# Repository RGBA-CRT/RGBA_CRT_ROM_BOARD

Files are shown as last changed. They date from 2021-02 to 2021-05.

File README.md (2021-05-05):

# RGBA_CRT ROM BOARD
+ 27C322 64Mbit ROM board for 8bit databus system
**※まだ不安定です**
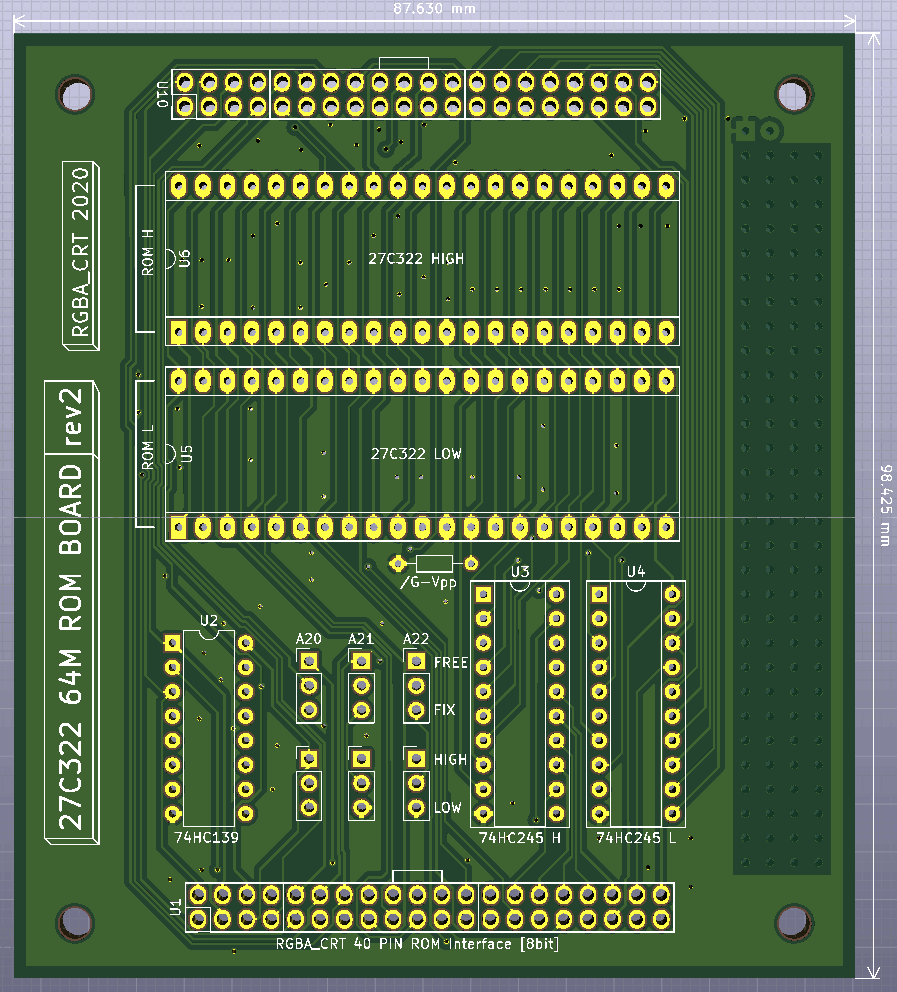
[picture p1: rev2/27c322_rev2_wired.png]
rev2 pcb


# about
+ 27C322を40ピンのピンヘッダに引き出す基板です
+ レトロコンシューマゲーム機やレトロコンピュータでの使用を想定しています
+ 引き出したピンヘッダにはIDC 40ピンリボンケーブルを接続します
	+ IDEケーブル（40芯, 全ピンが結線されているもの）が使用可能です
+ その他
	+ データバスは8bitに変換されます
	+ 27C322を2つ使って64Mbitに対応
	+ ROMのセレクトスイッチ搭載
+ この基板に対応したROMライターはこちら
	+ https://github.com/RGBA-CRT/FT232H-EPROM-Prog

# PIN ROM Interface pinout
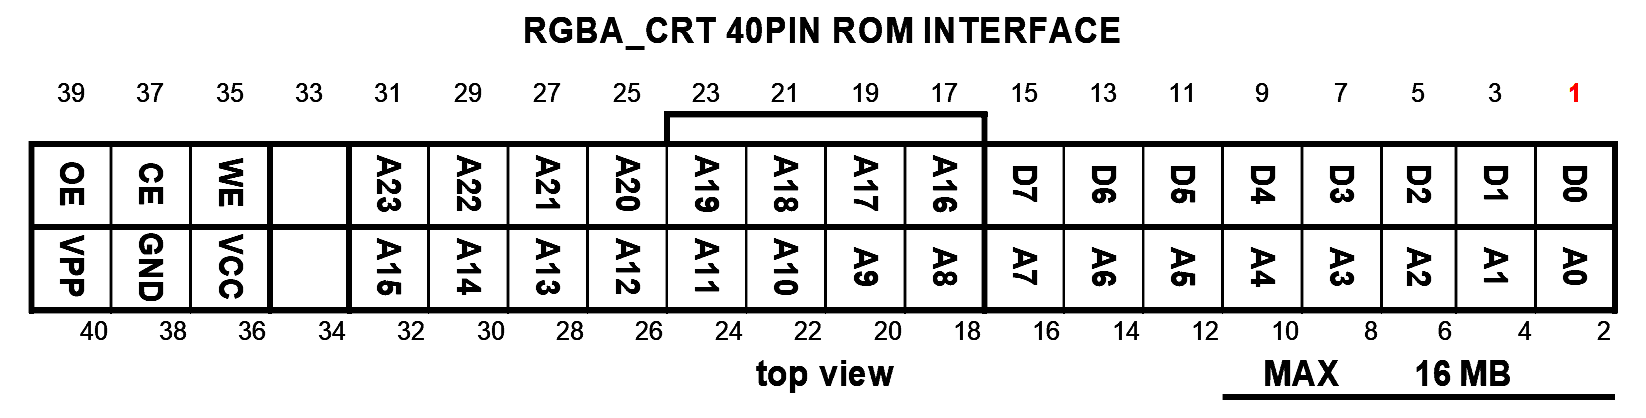
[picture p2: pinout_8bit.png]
pinout 8bit


+ data bus: 8bit
+ address bus: A0-A23 24bit
+ control bus: CE / OE / WE
+ VPP signal supported

# ROM select switch
+ A20, A21, A22の制御スイッチがあります
	+ A20 ... 8Mbit単位切り替え
	+ A21 ... 16Mbit単位切り替え
	+ A22 ... 32Mbit単位切り替え（EPROM切り替え）
+ FREEにするとそのアドレスビットの制御を機器側に委ねます
+ FIXにするとそのアドレスビットの制御をHIGH/LOWスイッチに委ねます
+ 使用例
	+ 1つの64MbitのROMとして基板を使いたい
		+ A20, A21, A22をすべてFREEにする
	+ 4つの16MbitのROMとして基板を使いたい
		+ A20をFREEにする
		+ A21, A22はFIXにする
			+ 2つのHIGH/LOWスイッチで4分割したROMの選択を行う

# 使用例
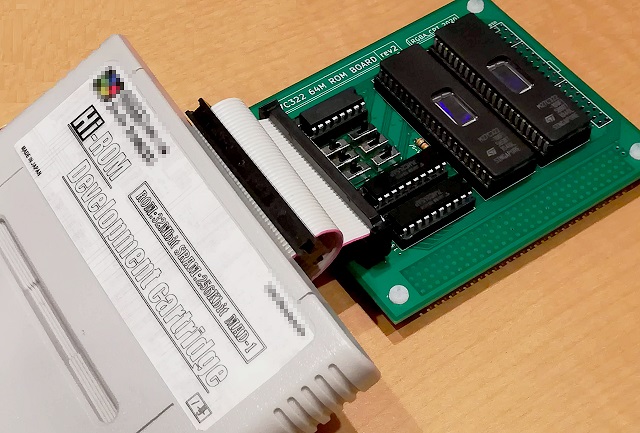
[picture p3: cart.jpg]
connection


# other
+ SNES/SFCのExHiROMとして使用する場合は、ROM焼き時と実機実行時でROM L, ROM Hを逆に取り付ける必要があります。
	+ ROMライターはファイルの順の通り次のように書き込みます
		+ ROM L: SNES BANK $C0-$FF
		+ ROM H: SNES BANK $40-$7F
	+ したがってSFCのカートリッジとして使うときにはROM LとROM Hを逆にする必要があります
+ おまけ
	+ この40 PIN ROM Interfaceに対応したユニバーサル基板
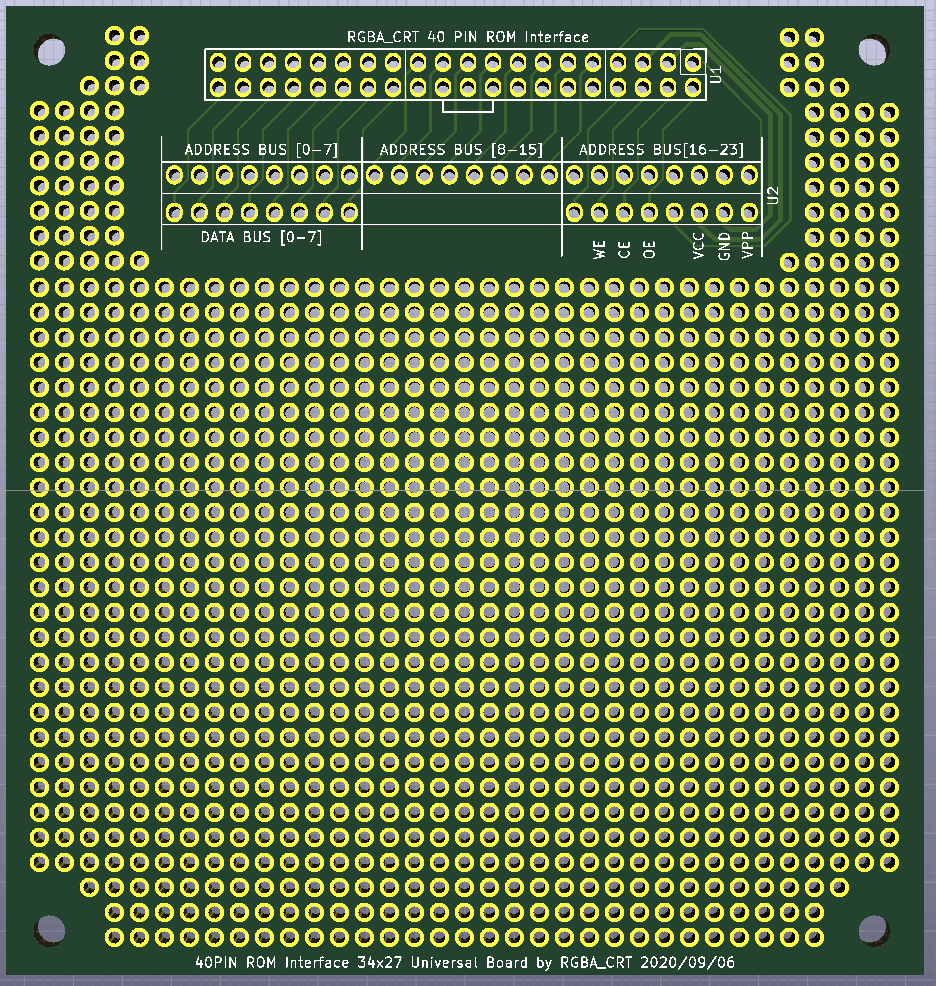
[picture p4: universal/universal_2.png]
univ pcb


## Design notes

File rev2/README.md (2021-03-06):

# RGBA_CRT_ROM_BOARD rev2
+ two ROM
+ 3 ROM select switch
+ low bytes are mapped to 0x0
+ high bytes are mapped to 0x1



# garber
[rev2.zip](rev2.zip)

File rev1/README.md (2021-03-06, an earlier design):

# RGBA_CRT_ROM_BOARD rev1
+ one ROM
+ 2 ROM select switch
+ low bytes are mapped to 0x000000-0x1FFFFF
+ high bytes are mapped to 0x200000-0x3FFFFF

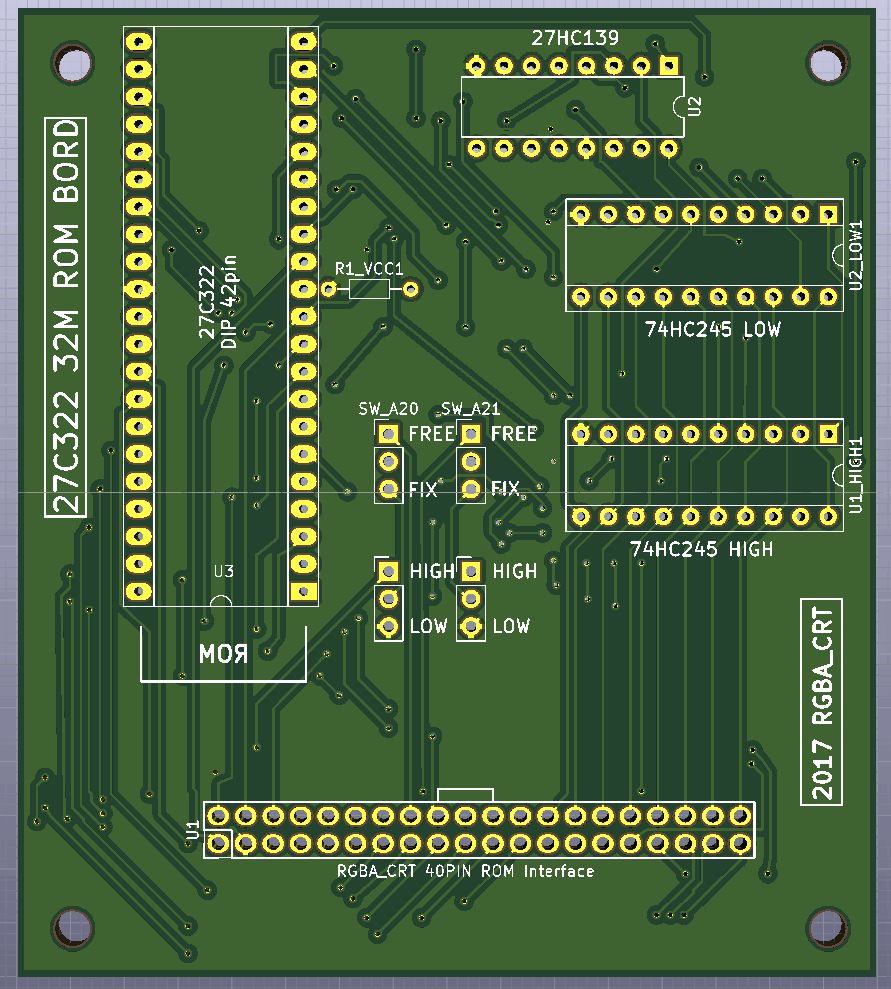
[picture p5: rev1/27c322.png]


# garber
[27c322Bord.zip](27c322Bord.zip)

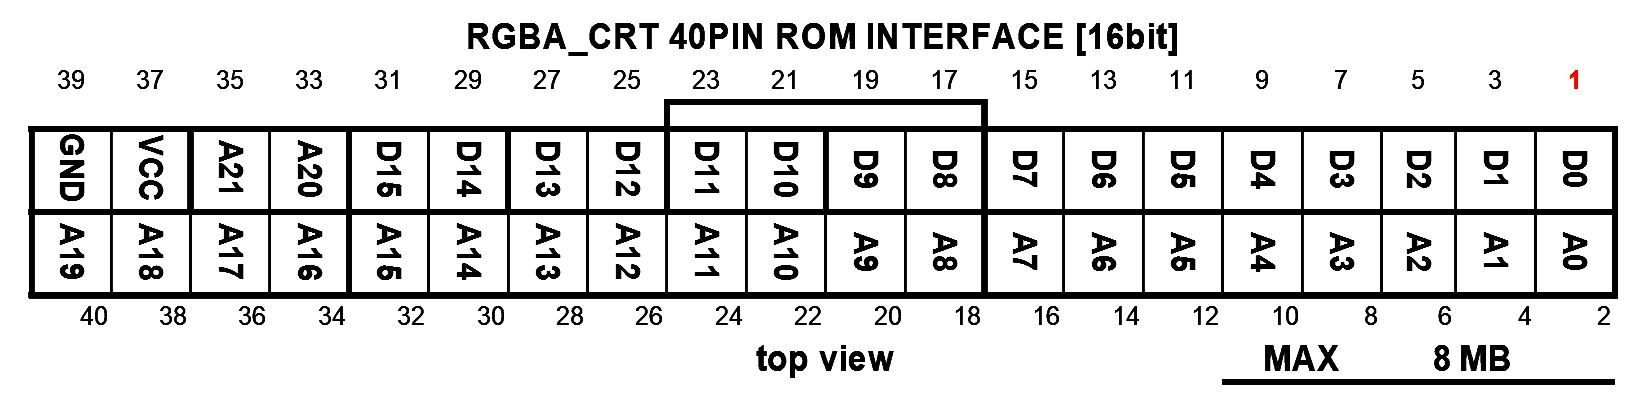
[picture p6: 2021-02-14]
pinout_16bit.png

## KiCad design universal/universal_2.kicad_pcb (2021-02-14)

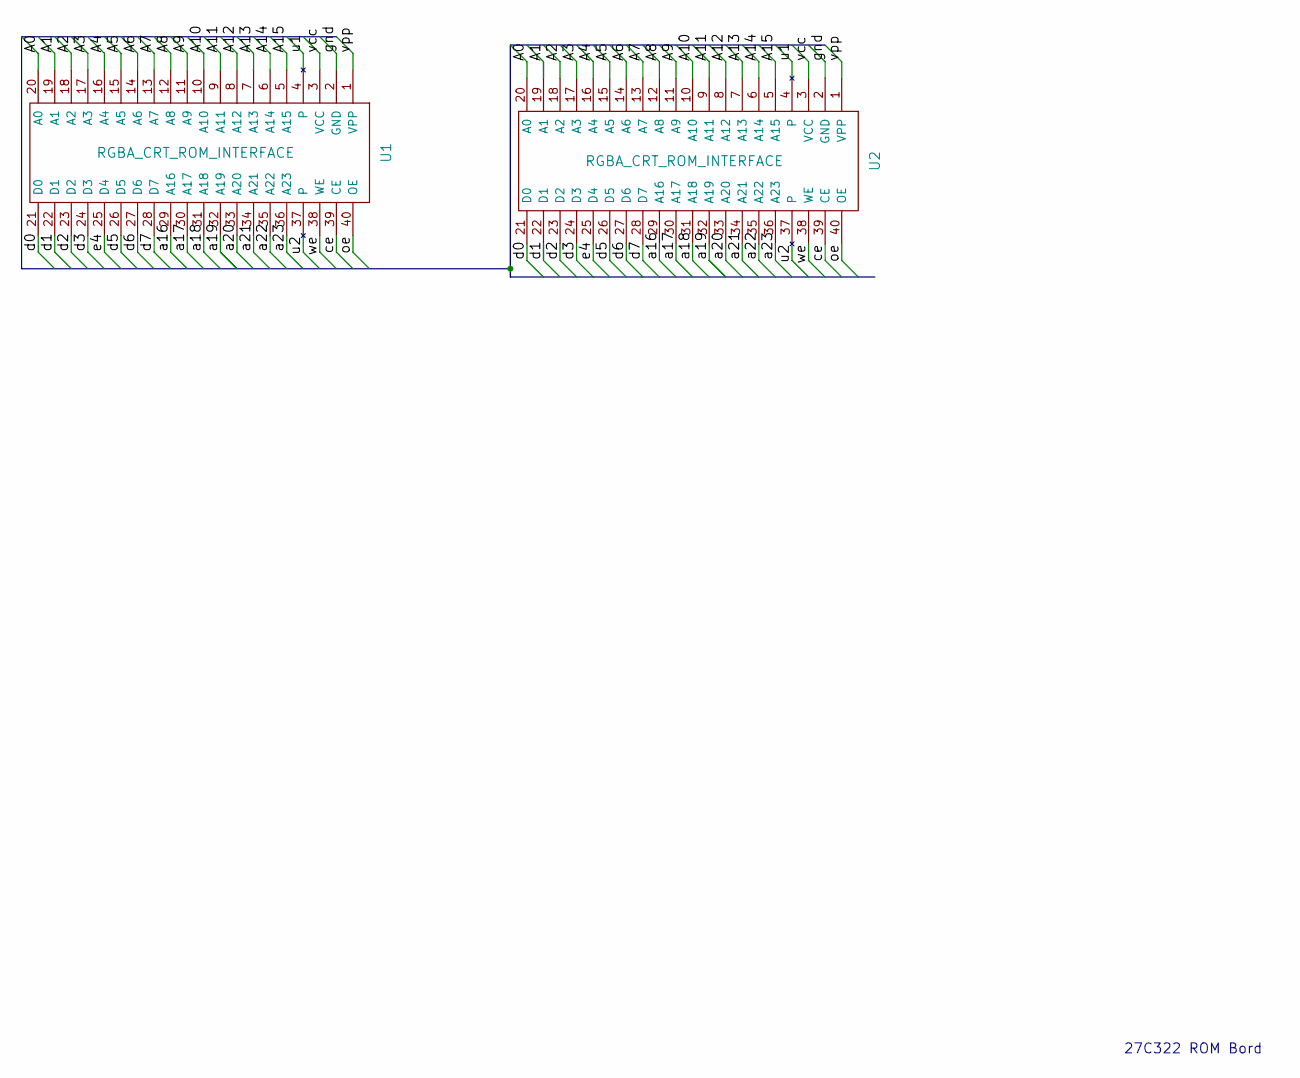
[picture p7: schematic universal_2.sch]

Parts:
U1: RGBA_CRT_ROM_INTERFACE
U2: RGBA_CRT_ROM_INTERFACE; RGBA_CRT_ROM_INTERFACE_DEBUG_HEDADER

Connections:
/A0: U1.20 (A0), U2.20 (A0)
/A1: U1.19 (A1), U2.19 (A1)
/A2: U1.18 (A2), U2.18 (A2)
/A3: U1.17 (A3), U2.17 (A3)
/A4: U1.16 (A4), U2.16 (A4)
/A5: U1.15 (A5), U2.15 (A5)
/A6: U1.14 (A6), U2.14 (A6)
/A7: U1.13 (A7), U2.13 (A7)
/A8: U1.12 (A8), U2.12 (A8)
/A9: U1.11 (A9), U2.11 (A9)
/A10: U1.10 (A10), U2.10 (A10)
/A11: U1.9 (A11), U2.9 (A11)
/A12: U1.8 (A12), U2.8 (A12)
/A13: U1.7 (A13), U2.7 (A13)
/A14: U1.6 (A14), U2.6 (A14)
/A15: U1.5 (A15), U2.5 (A15)
/a16: U1.29 (A16), U2.29 (A16)
/a17: U1.30 (A17), U2.30 (A17)
/a18: U1.31 (A18), U2.31 (A18)
/a19: U1.32 (A19), U2.32 (A19)
/a20: U1.33 (A20), U2.33 (A20)
/a21: U1.34 (A21), U2.34 (A21)
/a22: U1.35 (A22), U2.35 (A22)
/a23: U1.36 (A23), U2.36 (A23)
/ce: U1.39 (CE), U2.39 (CE)
/d0: U1.21 (D0), U2.21 (D0)
/d1: U1.22 (D1), U2.22 (D1)
/d2: U1.23 (D2), U2.23 (D2)
/d3: U1.24 (D3), U2.24 (D3)
/d5: U1.26 (D5), U2.26 (D5)
/d6: U1.27 (D6), U2.27 (D6)
/d7: U1.28 (D7), U2.28 (D7)
/e4: U1.25 (D4), U2.25 (D4)
/gnd: U1.2 (GND), U2.2 (GND)
/oe: U1.40 (OE), U2.40 (OE)
/u1: U1.4, U2.4
/u2: U1.37, U2.37
/vcc: U1.3 (VCC), U2.3 (VCC)
/vpp: U1.1 (VPP), U2.1 (VPP)
/we: U1.38 (WE), U2.38 (WE)

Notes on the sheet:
27C322 ROM Bord

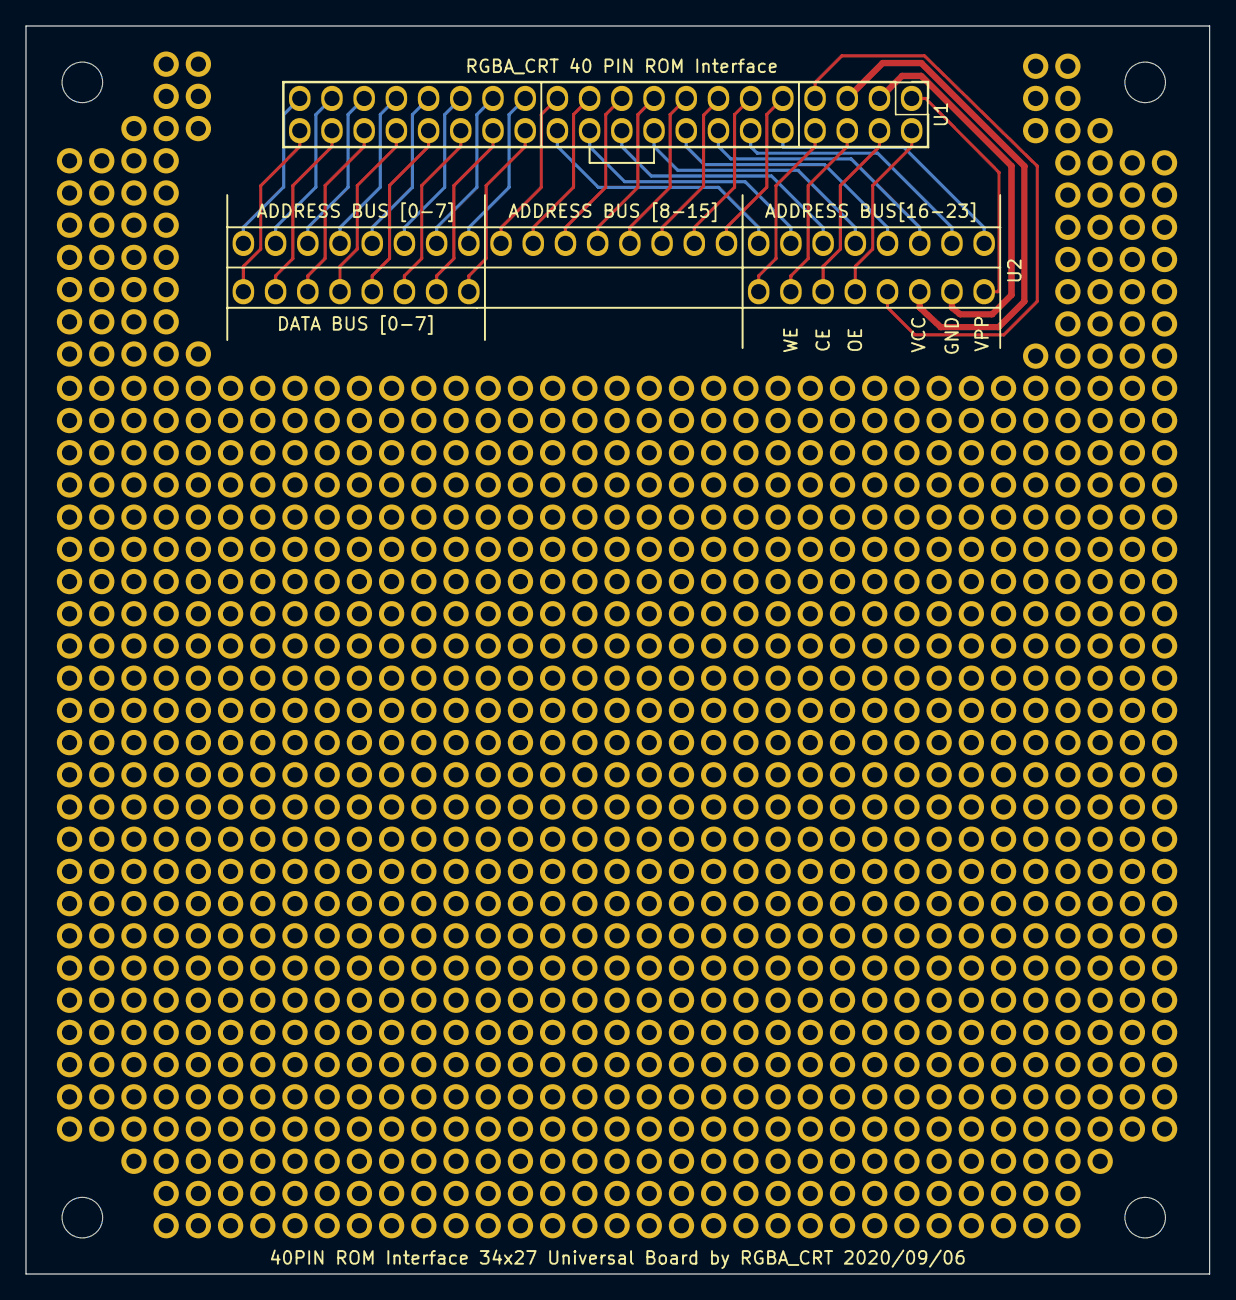
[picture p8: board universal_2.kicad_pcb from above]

Board: 2 copper layers, 93.3 x 98.4 mm, 9 parts (0 on the bottom side), 40 nets.

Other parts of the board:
HOLE1, HOLE2, HOLE3, HOLE4: MountingHole_3.2mm_M3
LEFT: SolderWirePad_4xSquare_0-8mmDrill
RIGHT: SolderWirePad_4xSquare_0-8mmDrill
UBIVERSAL: SolderWirePad_4xSquare_0-8mmDrill

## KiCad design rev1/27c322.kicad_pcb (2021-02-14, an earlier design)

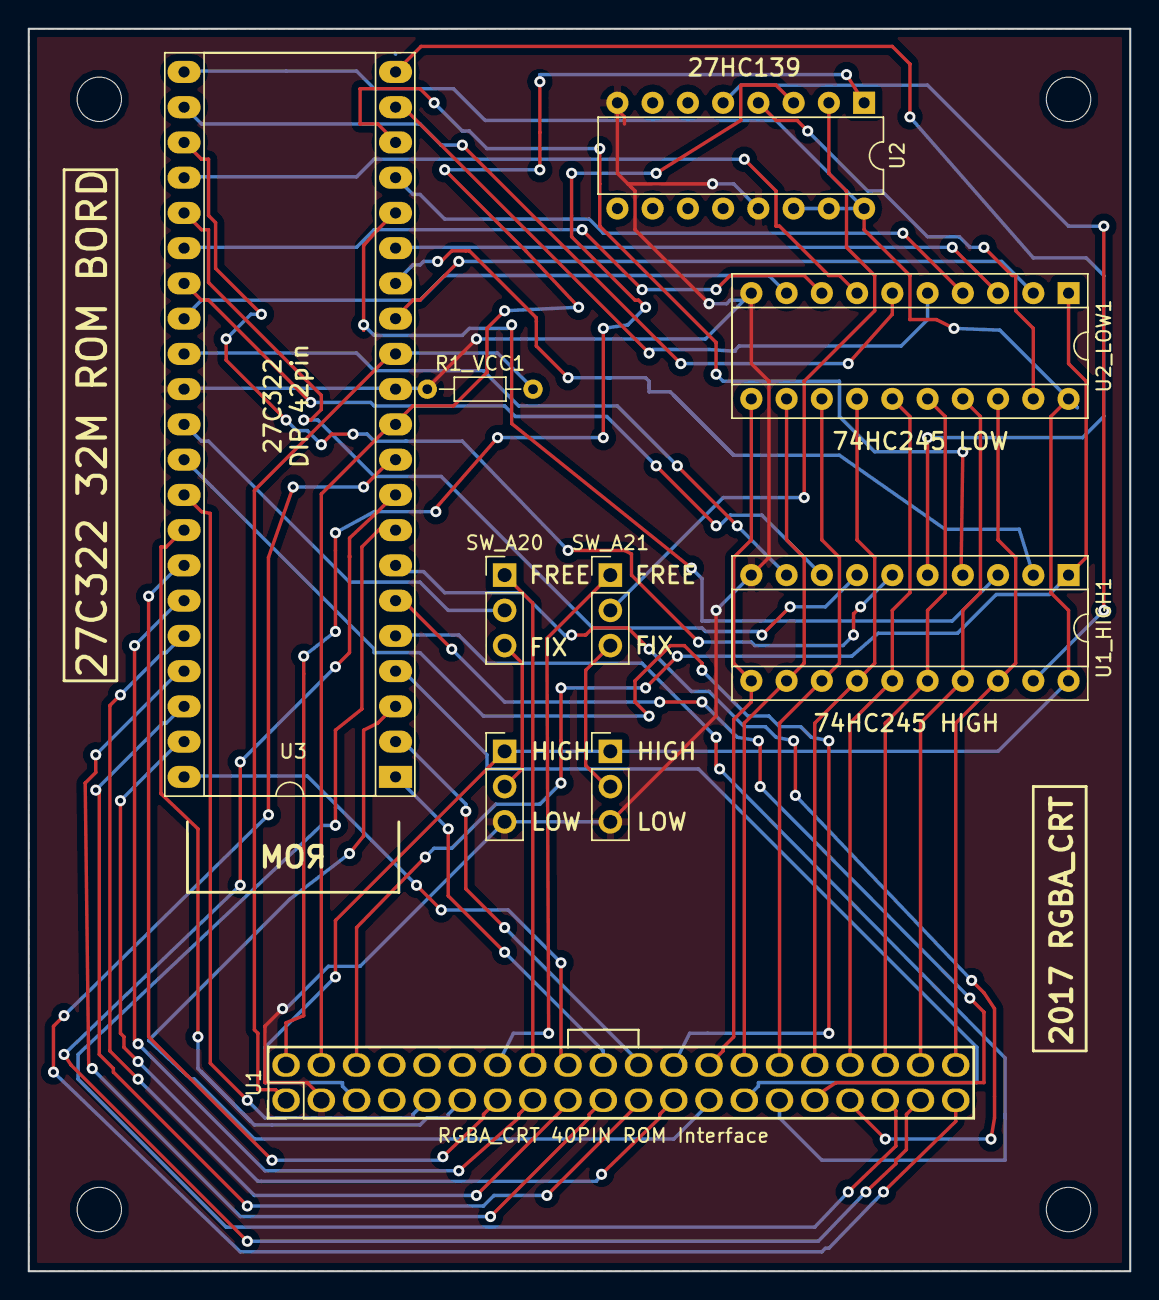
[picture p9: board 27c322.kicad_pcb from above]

Board: 2 copper layers, 79.4 x 89.5 mm, 14 parts (0 on the bottom side), 58 nets.

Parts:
MOUNTU+: MountingHole_3.2mm_M3
MOUNT_BR: MountingHole_3.2mm_M3
MOUNT_LB: MountingHole_3.2mm_M3
MOUNT_UR: MountingHole_3.2mm_M3
R1_VCC1: R; R_Axial_DIN0204_L3.6mm_D1.6mm_P7.62mm_Horizontal
SWA21_HL1: Switch_SPDT_x2; Pin_Header_Straight_1x03_Pitch2.54mm
SW_A20, SW_A20_HL1, SW_A21: Switch_SPDT_x2; Pin_Header_Straight_1x03_Pitch2.54mm
U1: RGBA_CRT_ROM_INTERFACE
U1_HIGH1, U2_LOW1: 74HC245; DIP-20_W7.62mm_Socket
U2: 74LS139; DIP-16_W7.62mm
U3: 27C322; DIP-42_W15.24mm_Socket_LongPads

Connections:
+5V: SWA21_HL1.1, SW_A20_HL1.1, U1.3, U1_HIGH1.20, U2.14, U2.15, U2.16, U2_LOW1.20, U3.22
/A0: U1.20, U3.10
/A1: U1.19, U3.9
/A2: U1.18, U3.8
/A3: U1.17, U3.7
/A4: U1.16, U3.6
/A5: U1.15, U3.5
/A6: U1.14, U3.4
/A7: U1.13, U3.3
/A8: U1.12, U3.41
/A9: U1.11, U3.40
/A10: U1.10, U3.39
/A11: U1.9, U3.38
/A12: U1.8, U3.37
/A13: U1.7, U3.36
/A14: U1.6, U3.35
/A15: U1.5, U3.34
/A16: U1.29, U3.33
/A17: U1.30, U3.2
/A18: U1.31, U3.1
/A19: U1.32, U3.42
/A20: SW_A20.2, U3.32
/A21: SW_A21.2, U2.2
/D0: U1.21, U1_HIGH1.18, U2_LOW1.18
/D1: U1.22, U1_HIGH1.17, U2_LOW1.17
/D2: U1.23, U1_HIGH1.16, U2_LOW1.16
/D3: U1.24, U1_HIGH1.15, U2_LOW1.15
/D4: U1.25, U1_HIGH1.14, U2_LOW1.14
/D5: U1.26, U1_HIGH1.13, U2_LOW1.13
/D6: U1.27, U1_HIGH1.12, U2_LOW1.12
/D7: U1.28, U1_HIGH1.11, U2_LOW1.11
/FIX_A20: SW_A20.3, SW_A20_HL1.2
/FIX_A21: SWA21_HL1.2, SW_A21.3
/FREE_A20: SW_A20.1, U1.33
/FREE_A21: SW_A21.1, U1.34
/Q0: U2_LOW1.2, U3.14
/Q1: U2_LOW1.3, U3.16
/Q2: U2_LOW1.4, U3.18
/Q3: U2_LOW1.5, U3.20
/Q4: U2_LOW1.6, U3.23
/Q5: U2_LOW1.7, U3.25
/Q6: U2_LOW1.8, U3.27
/Q7: U2_LOW1.9, U3.29
/Q8: U1_HIGH1.2, U3.15
/Q9: U1_HIGH1.3, U3.17
/Q10: U1_HIGH1.4, U3.19
/Q11: U1_HIGH1.5, U3.21
/Q12: U1_HIGH1.6, U3.24
/Q13: U1_HIGH1.7, U3.26
/Q14: U1_HIGH1.8, U3.28
/Q15: U1_HIGH1.9, U3.30
GND: R1_VCC1.1, SWA21_HL1.3, SW_A20_HL1.3, U1.2, U1_HIGH1.10, U2.8, U2.13, U2_LOW1.10, U3.12, U3.31
unnamed: R1_VCC1.2, U1.1, U3.13
unnamed: U1.38, U1_HIGH1.1, U2_LOW1.1
unnamed: U1.39, U2.1, U3.11
unnamed: U1.40, U2.3
unnamed: U1_HIGH1.19, U2.5
unnamed: U2.4, U2_LOW1.19

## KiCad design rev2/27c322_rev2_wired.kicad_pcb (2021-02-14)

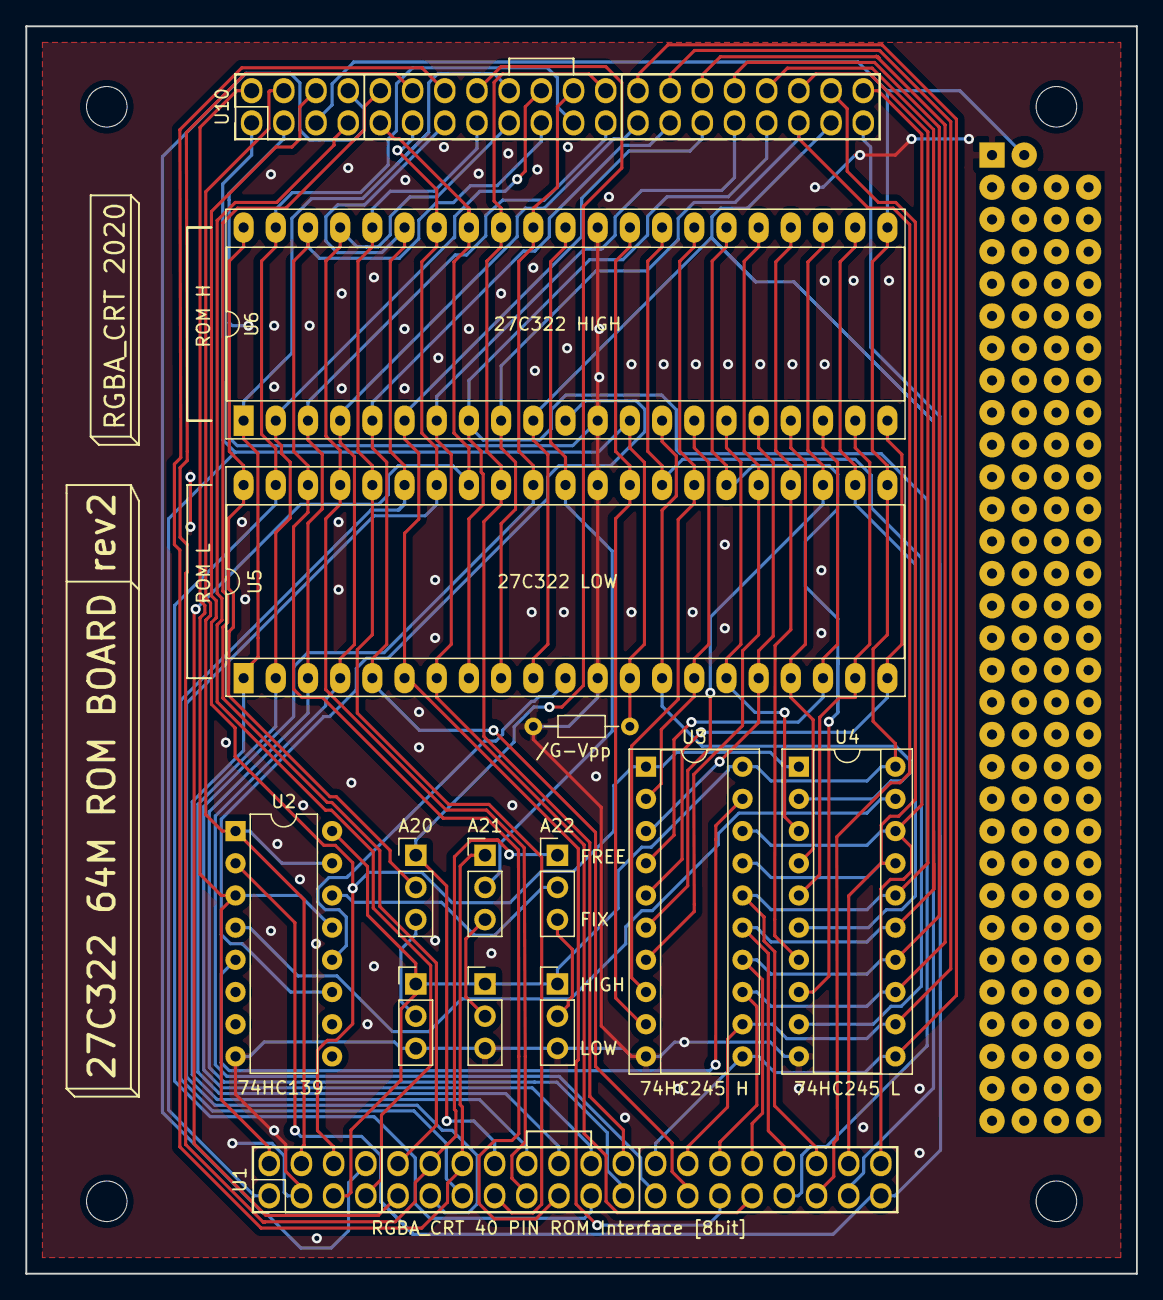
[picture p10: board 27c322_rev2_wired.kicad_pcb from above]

Board: 2 copper layers, 87.6 x 98.4 mm, 21 parts (0 on the bottom side), 66 nets.

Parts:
/G-Vpp: R; R_Axial_DIN0204_L3.6mm_D1.6mm_P7.62mm_Horizontal
A20, A21, A22: Switch_SPDT_x2; Pin_Header_Straight_1x03_Pitch2.54mm
DR1, DR2, DR3, DR4: MountingHole_3.2mm_M3
GND: SolderWirePad_single_0-8mmDrill
SWA21_HL1: Switch_SPDT_x2; Pin_Header_Straight_1x03_Pitch2.54mm
SW_A20_HL1, SW_A22_HL1: Switch_SPDT_x2; Pin_Header_Straight_1x03_Pitch2.54mm
U1, U10: RGBA_CRT_ROM_INTERFACE
U2: 74LS139; DIP-16_W7.62mm
U3: 74HC245_H; DIP-20_W7.62mm_Socket
U4: 74HC245_L; DIP-20_W7.62mm_Socket
U5: 27C322_L; DIP-42_W15.24mm_Socket_LongPads
U6: 27C322_H; DIP-42_W15.24mm_Socket_LongPads
Universal Area: SolderWirePad_4xSquare_0-8mmDrill
VCC: SolderWirePad_single_0-8mmDrill

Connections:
+5V: SWA21_HL1.1, SW_A20_HL1.1, SW_A22_HL1.1, U1.3, U2.16, U3.20, U4.20, U5.22, U6.22, U10.3, VCC.1
/A0: U1.20, U2.2, U10.20
/A1: U1.19, U5.10, U6.10, U10.19
/A2: U1.18, U5.9, U6.9, U10.18
/A3: U1.17, U5.8, U6.8, U10.17
/A4: U1.16, U5.7, U6.7, U10.16
/A5: U1.15, U5.6, U6.6, U10.15
/A6: U1.14, U5.5, U6.5, U10.14
/A7: U1.13, U5.4, U6.4, U10.13
/A8: U1.12, U5.3, U6.3, U10.12
/A9: U1.11, U5.41, U6.41, U10.11
/A10: U1.10, U5.40, U6.40, U10.10
/A11: U1.9, U5.39, U6.39, U10.9
/A12: U1.8, U5.38, U6.38, U10.8
/A13: U1.7, U5.37, U6.37, U10.7
/A14: U1.6, U5.36, U6.36, U10.6
/A15: U1.5, U5.35, U6.35, U10.5
/A16: U1.29, U5.34, U6.34, U10.29
/A17: U1.30, U5.33, U6.33, U10.30
/A18: U1.31, U5.2, U6.2, U10.31
/A19: U1.32, U5.1, U6.1, U10.32
/A20: A20.2, U5.42, U6.42
/A21: A21.2, U5.32, U6.32
/A22: A22.2, U2.14
/D0: U1.21, U3.18, U4.18, U10.21
/D1: U1.22, U3.17, U4.17, U10.22
/D2: U1.23, U3.16, U4.16, U10.23
/D3: U1.24, U3.15, U4.15, U10.24
/D4: U1.25, U3.14, U4.14, U10.25
/D5: U1.26, U3.13, U4.13, U10.26
/D6: U1.27, U3.12, U4.12, U10.27
/D7: U1.28, U3.11, U4.11, U10.28
/IF_A20: A20.1, U1.33, U10.33
/IF_A21: A21.1, U1.34, U10.34
/IF_A22: A22.1, U1.35, U10.35
/IF_A23: U1.36, U10.36
/OE: U1.40, U2.3, U2.13, U10.40
/Q0: U4.2, U5.14, U6.14
/Q1: U4.3, U5.16, U6.16
/Q2: U4.4, U5.18, U6.18
/Q3: U4.5, U5.20, U6.20
/Q4: U4.6, U5.23, U6.23
/Q5: U4.7, U5.25, U6.25
/Q6: U4.8, U5.27, U6.27
/Q7: U4.9, U5.29, U6.29
/Q8: U3.2, U5.15, U6.15
/Q9: U3.3, U5.17, U6.17
/Q10: U3.4, U5.19, U6.19
/Q11: U3.5, U5.21, U6.21
/Q12: U3.6, U5.24, U6.24
/Q13: U3.7, U5.26, U6.26
/Q14: U3.8, U5.28, U6.28
/Q15: U3.9, U5.30, U6.30
GND: /G-Vpp.2, GND.1, SWA21_HL1.3, SW_A20_HL1.3, SW_A22_HL1.3, U1.2, U2.8, U3.10, U4.10, U5.12, U5.31, U6.12, U6.31, U10.2
unnamed: /G-Vpp.1, U1.1, U5.13, U6.13, U10.1
unnamed: A21.3, SWA21_HL1.2
unnamed: A20.3, SW_A20_HL1.2
unnamed: A22.3, SW_A22_HL1.2
unnamed: U1.4, U10.4
unnamed: U1.37, U10.37
unnamed: U1.38, U3.1, U4.1, U10.38
unnamed: U1.39, U2.1, U2.15, U10.39
unnamed: U2.4, U4.19
unnamed: U2.5, U3.19
unnamed: U2.11, U6.11
unnamed: U2.12, U5.11

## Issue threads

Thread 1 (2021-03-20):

SFCでデータが化ける

RGBA-CRT, 2021-03-20:
# 確認ソフト
バグりやすい順
+ Bad Apple!!!
+ ロマンシング東方
+ FF6-T

# ケーブル長
+ HiROM Cart 1号：15cm
   + FF6-TのOPは起動する、それ以外はパスコン付きでも動作せず
   + SRAM 256kbit ::: 32K x 8bit
+ HiROM Cart 2号：5.5cm
   + Bad Appleがバグりながらも完走
   + ロマンシング東方のOP完走、New Gameから進める
   + SRAM 64kbit ::: 8K x 8bit

# パスコン
パスコンをつけるとオーバーシュートとアンダーシュートが若干改善するっぽい？
+ 74HC245と74HC139に1μFのセラコン
+ 27C322に0.1μFのセラコンと4.7μFの電解コン
   + 根拠はデータシート

あとはリンギング低減にターミネータを使うか？ 集合抵抗がよさそう。

実機マスクROMでもオーバーシュート・アンダーシュート・リンギングは発生している。
パスコンつければ同じレベルまで改善する

# ロジックIC
+ 74HC139
   + ★SN74HC139N
       + BadAppleの音がバグりながらも完走, TCより安定
       + 遅延 35ns@4.5V 50pF
       + /G 遅延 35ns@4.5V 50pF
   + TC74HCT139AP
       + 不安定, HCTだから？
       + 遅延 38ns@4.5V 50pF
       + /G 遅延 34ns@4.5V 50pF
   + SN74AHC139N ... 未テスト, 目標はBad Appleがバグなく動くこと
+ 74HC245
   + SN74HC245N ... Bad Applleの音がバグりながらも完走
       + 伝搬遅延 26ns@4.5V 50pF
       + /OE 遅延 54ns@4.5V 50pF
   + ★TC74HC245AP ... 手持ちの中では一番安定
       + 伝搬遅延 23ns@4.5V 50pF
       + /OE 遅延 38ns@4.5V 50pF
   + SN74**A**HC245N ... 購入してテスト予定, 目標はBad Appleがバグなく動くこと
   + 245についてはSNとTCで違いがなさそう

# その他
+ A0にByte Selectを使ったのが間違いでは？
   + BadAppleはともかくロマ東やFF6-Tを見る限り割と頻繁にA22も動いているのでどこにByte Selectを当てても同じ問題が起こる気がする。
   + それならちゃんとした部品を選定して使うほうが良いのでは。
   + ただA0より変動確率は低そうなので改善はしそうではある。

RGBA-CRT, 2021-03-20:
# PCB
セラコンだけで今のところ差はみられない。

+ 基板No1
   + セラコン, 電解コン実装
   + 電源ライン強化

+ 基板No2
   + セラコン実装

RGBA-CRT, 2021-03-27:
SN74HC139N＋TC74HC245AP でもたまに停止する

RGBA-CRT, 2021-03-27:
1号でもロマ東が動作するものの画がバグる
やはりケーブル長は短い覇王がよさそう

RGBA-CRT, 2021-03-27:
AHC139+AHC245＋ロマンシング東方でもバグ発生
HC139に戻すとバグらない
以下推測
・バスバッファは3つのうちどれでもOK
・74HC139はSN74HC139が良い
　・AHCはスペックが良く特性が合わないのか？パスコンに必要な容量などが違う？
　・TC74HCT139APが非常に不安定なのはHCTだからだと思われる
・74LS系だとどうなのだろうか...　ケーブルもあるので74ACとかも実験の余地がありそう

RGBA-CRT, 2021-03-27:
1号（ケーブル長が長いもの）だとすべてAHCに揃えないと動かない。しかし動いたとしても主にグラフィックがバグる。

RGBA-CRT, 2021-03-27:
追加動作確認
・BadApple Lost version ... AHC245 + AHC139
・SuperDemoWorld ... AHC245 + AHC139
・SDK2 クレムリンの逆襲 ... AHC245 + AHC139

RGBA-CRT, 2021-03-28:
スタフォのが50MHzで動かない。rev1のHighSpeed改造版では動いているのでスペックが低下している？
ケーブルは長い方でしか動かない
